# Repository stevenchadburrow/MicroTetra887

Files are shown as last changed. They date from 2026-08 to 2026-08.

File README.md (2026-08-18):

# MicroTetra887
<b>Two-player "Tetra" through 16-color VGA on a PIC16F887</b><br>

The goal of this project was a challenge to do more with less.  I have used the PIC24 and PIC32 various times to generate VGA signals and play video games, but the PIC16 has far less capability.  "Tetra" is very easy to implement and one of my favorite games, so it was the target for this device.  Space allowed for there to be two players simultaneously.

Specifications:<br>
- Only IC is the PIC16F887<br>
- Runs at 5 MIPS (20 MHz clock)<br>
- 368 bytes of RAM<br>
- VGA resolution of 24x22 pixels at 16 colors<br>
- Two-player "Tetra" through homebrew or Genesis controllers<br>
- PCB's double as both the console and controllers<br>

<table>
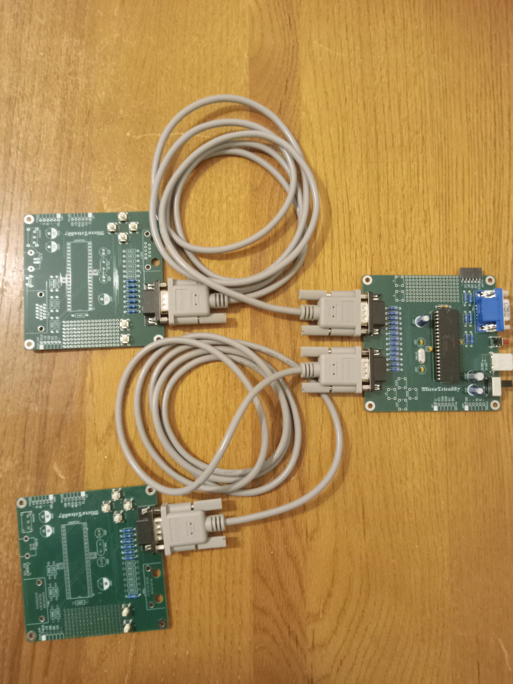
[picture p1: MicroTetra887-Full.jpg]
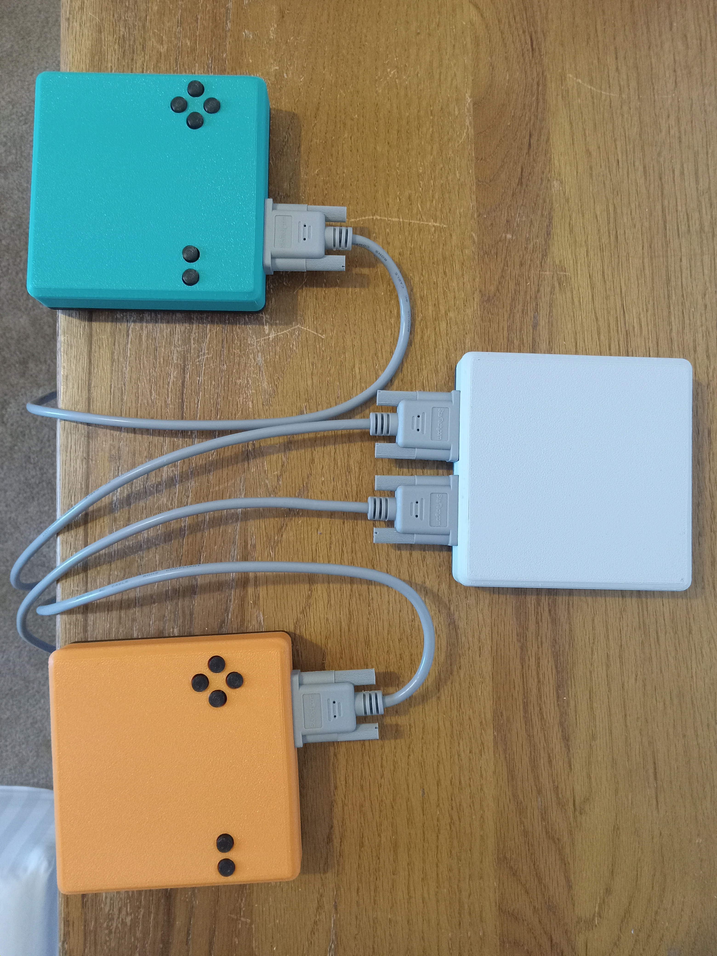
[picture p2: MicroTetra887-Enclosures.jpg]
  <tr><td></td><td></td></tr>
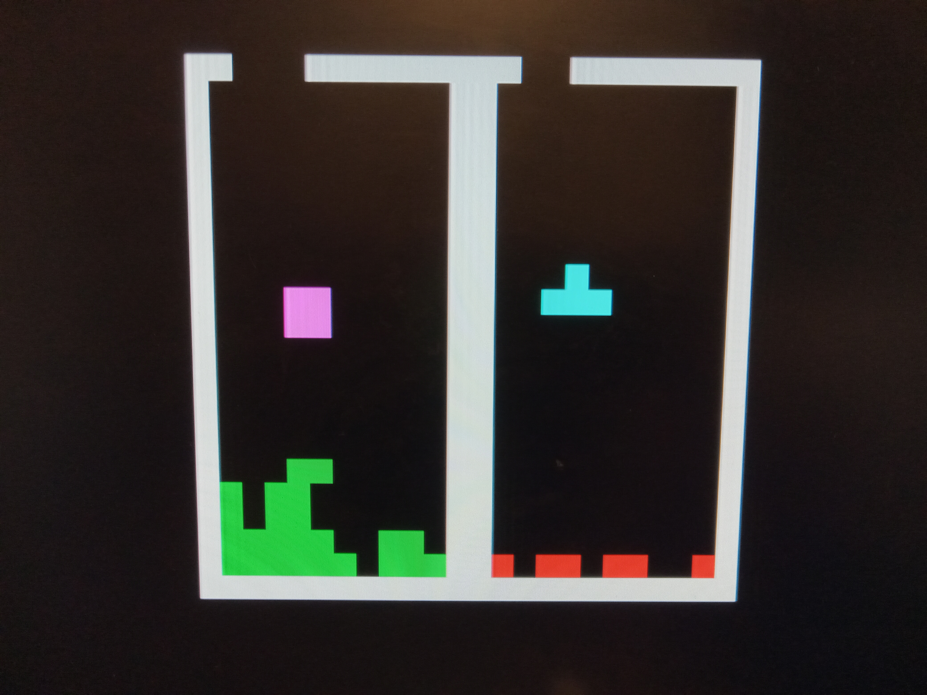
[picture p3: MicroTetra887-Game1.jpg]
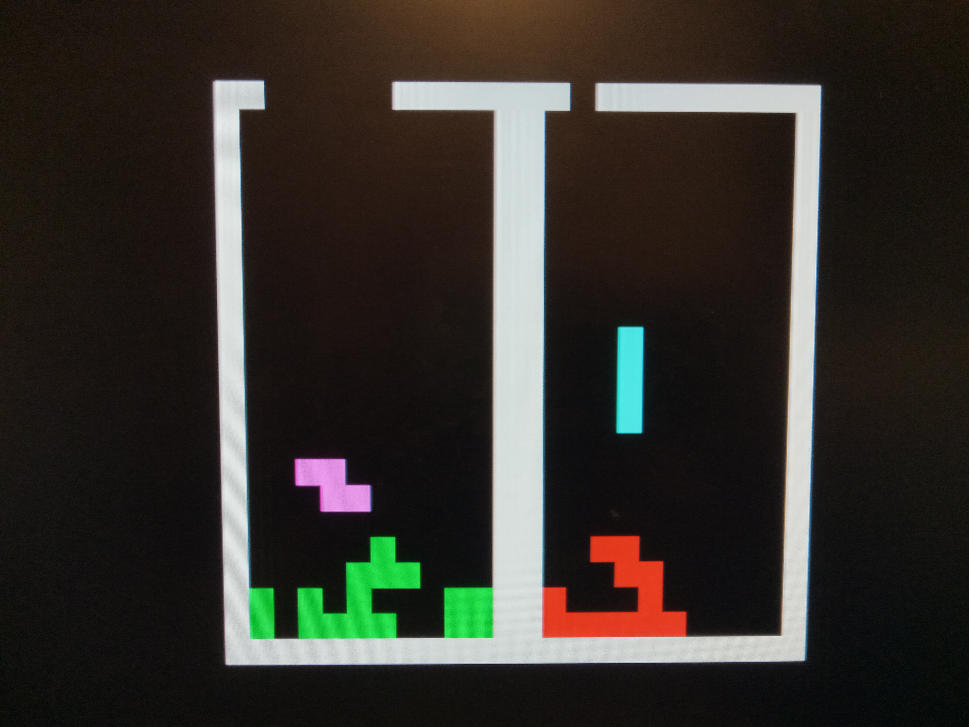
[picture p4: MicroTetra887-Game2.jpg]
  <tr><td></td><td></td></tr>
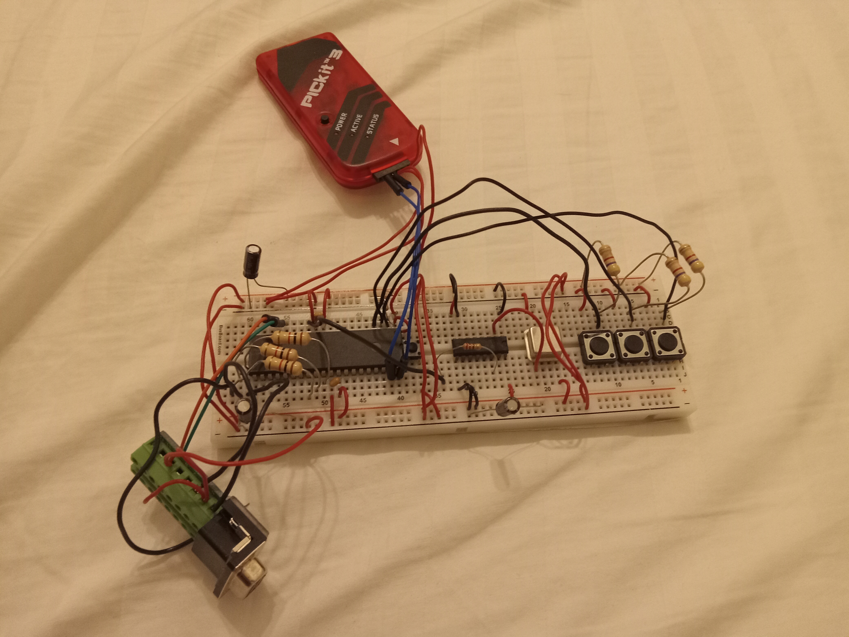
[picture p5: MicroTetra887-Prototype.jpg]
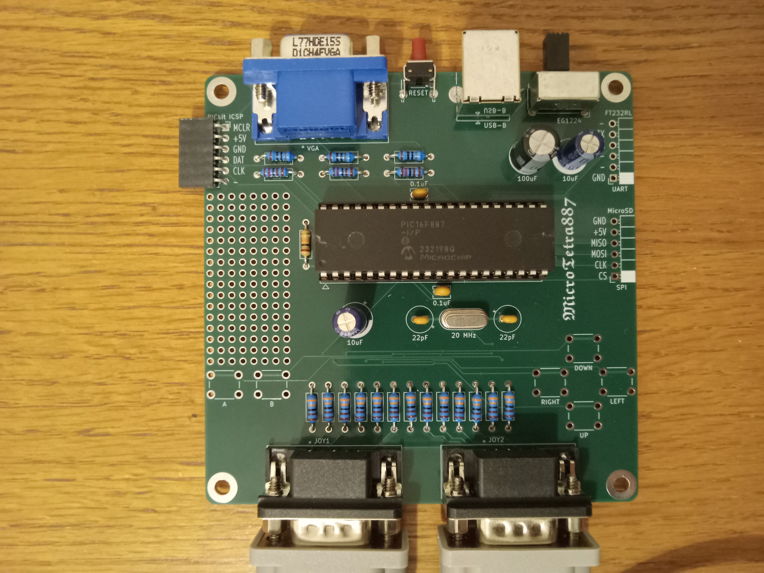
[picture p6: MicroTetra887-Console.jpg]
  <tr><td></td><td></td></tr>
</table>

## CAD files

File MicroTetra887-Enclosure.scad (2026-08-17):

// MicroTetra887

module radiusedblock(xlen,ylen,zlen,radius) {
	hull() {
		translate([radius,radius,radius]) sphere(r=radius);
		translate([xlen + radius , radius , radius]) sphere(r=radius);
		translate([radius , ylen + radius , radius]) sphere(r=radius);    
		translate([xlen + radius , ylen + radius , radius]) sphere(r=radius);
		translate([radius , radius , zlen + radius]) sphere(r=radius);
		translate([xlen + radius , radius , zlen + radius]) sphere(r=radius);
		translate([radius,ylen + radius,zlen + radius]) sphere(r=radius);
		translate([xlen + radius,ylen + radius,zlen + radius]) sphere(r=radius);
	}
}

$fn = 20; // higher detail to curves

// mode -> 0 = console, mode -> 1 = controller1, mode -> 2 = controller2
mode = 0;

// half -> 0 = both, half -> 1 = top, half -> 2 = bottom, half -> 3 = buttons
half = 0;

// up, down, left right, A, B
bpx = [ 87.5, 87.5, 95.25, 79.75, 4.75, 15.75 ];
bpy = [ 80.0, 64.5, 72.25, 72.25, 72.25, 72.25 ];

scale([1,-1,1])
{
	difference()
	{
		// outside
		translate([-5,-5,-5])
		{
			radiusedblock(100,100,20,5);
		}
		
		// inside
		translate([-1,-1,0])
		{
			cube([102,102,20]);
		}
			
        if (mode == 0)
        {
            // vga
            translate([11.0,-10,5])
            {
                cube([33.0,20,14]);
            }
            
            // reset
            translate([50.0,-10,9])
            {
                rotate([-90,0,0])
                {
                    cylinder(20,3,3);
                }
            }
                
            // usb
            translate([58.0,-10,5])
            {
                cube([14.0,20,12]);
            }
            
            // switch
            translate([77.0,-10,7])
            {
                cube([11.0,20,7]);
            }
        }
        
        if (mode == 0 || mode == 1)
        {
            // joy1
            translate([13.5,90,5])
            {
                cube([33.0,20,14]);
            }
        }
        
        if (mode == 0 || mode == 2)
        {
            // joy2
            translate([53.5,90,5])
            {
                cube([33.0,20,14]);
            }
        }
        
        if (mode == 1 || mode == 2)
        {
            // buttons
            for (i = [0:5])
            {
                translate([bpx[i], bpy[i], 10])
                {
                    cylinder(20,4,4);
                }
            }
        }
		
		// screw holes
		translate([4.0,4.0,5])
		{
			rotate([180,0,0])
			{
				cylinder(20,2.5,2.5);
			}
		}
		translate([96.0,4.0,5])
		{
			rotate([180,0,0])
			{
				cylinder(20,2.5,2.5);
			}
		}
		translate([4.0,96.0,5])
		{
			rotate([180,0,0])
			{
				cylinder(20,2.5,2.5);
			}
		}
		translate([96.0,96.0,5])
		{
			rotate([180,0,0])
			{
				cylinder(20,2.5,2.5);
			}
		}
		
        if (half == 1 || half == 3)
        {
            // comment out for top only
            translate([-10,-10,-10])
            {
                cube([120,120,10+5]);
            }
        }
		
        if (half == 2 || half == 3)
        {
            // comment out for bottom only
            translate([-10,-10,5])
            {
                cube([120,120,30]);
            }
        }
	}
	
	difference()
	{
		union()
		{
			// screw supports
			translate([4,4,0])
			{
				difference()
				{
					cylinder(20,4.5,4.5);
					cylinder(20,1.0,1.0);
				}
			}
			translate([96,4,0])
			{
				difference()
				{
					cylinder(20,4.5,4.5);
					cylinder(20,1.0,1.0);
				}
			}
			translate([4,96,0])
			{
				difference()
				{
					cylinder(20,4.5,4.5);
					cylinder(20,1.0,1.0);
				}
			}
			translate([96,96,0])
			{
				difference()
				{
					cylinder(20,4.5,4.5);
					cylinder(20,1.0,1.0);
				}
			}
			
			// support supports
			translate([1,1,0])
			{
				cylinder(20,3,3);
			}
			translate([99,1,0])
			{
				cylinder(20,3,3);
			}
			translate([1,99,0])
			{
				cylinder(20,3,3);
			}
			translate([99,99,0])
			{
				cylinder(20,3,3);
			}
			
            if (mode == 1 || mode == 2)
            {
                // button supports
                for (i = [0:5])
                {
                    translate([bpx[i], bpy[i], 15])
                    {
                        difference()
                        {
                            cylinder(5,6,6);
                            cylinder(5,4,4);
                        }
                    }
                }
            }
		}
		
		// pcb
		translate([-10,-10,5-1.6])
		{
			cube([120,120,1.6]);
		}
		
        if (half == 1 || half == 3)
        {
            // comment out for top only
            translate([-10,-10,-10])
            {
                cube([120,120,10+5]);
            }
        }
		
        if (half == 2 || half == 3)
        {
            // comment out for bottom only
            translate([-10,-10,5])
            {
                cube([120,120,30]);
            }
        }
	}
}

module button()
{
	difference()
	{
		union()
		{
			cylinder(15, 3.5, 3.5);
			cylinder(2, 5, 5);
			intersection()
			{
				sphere(17);
				cylinder(100, 3.5, 3.5);
			}
		}
		translate([-1.35, -1.35, 0])
		{
			cube([2.7, 2.7, 3.0]);
		}
	}
}

if (half == 3)
{
    button();
}

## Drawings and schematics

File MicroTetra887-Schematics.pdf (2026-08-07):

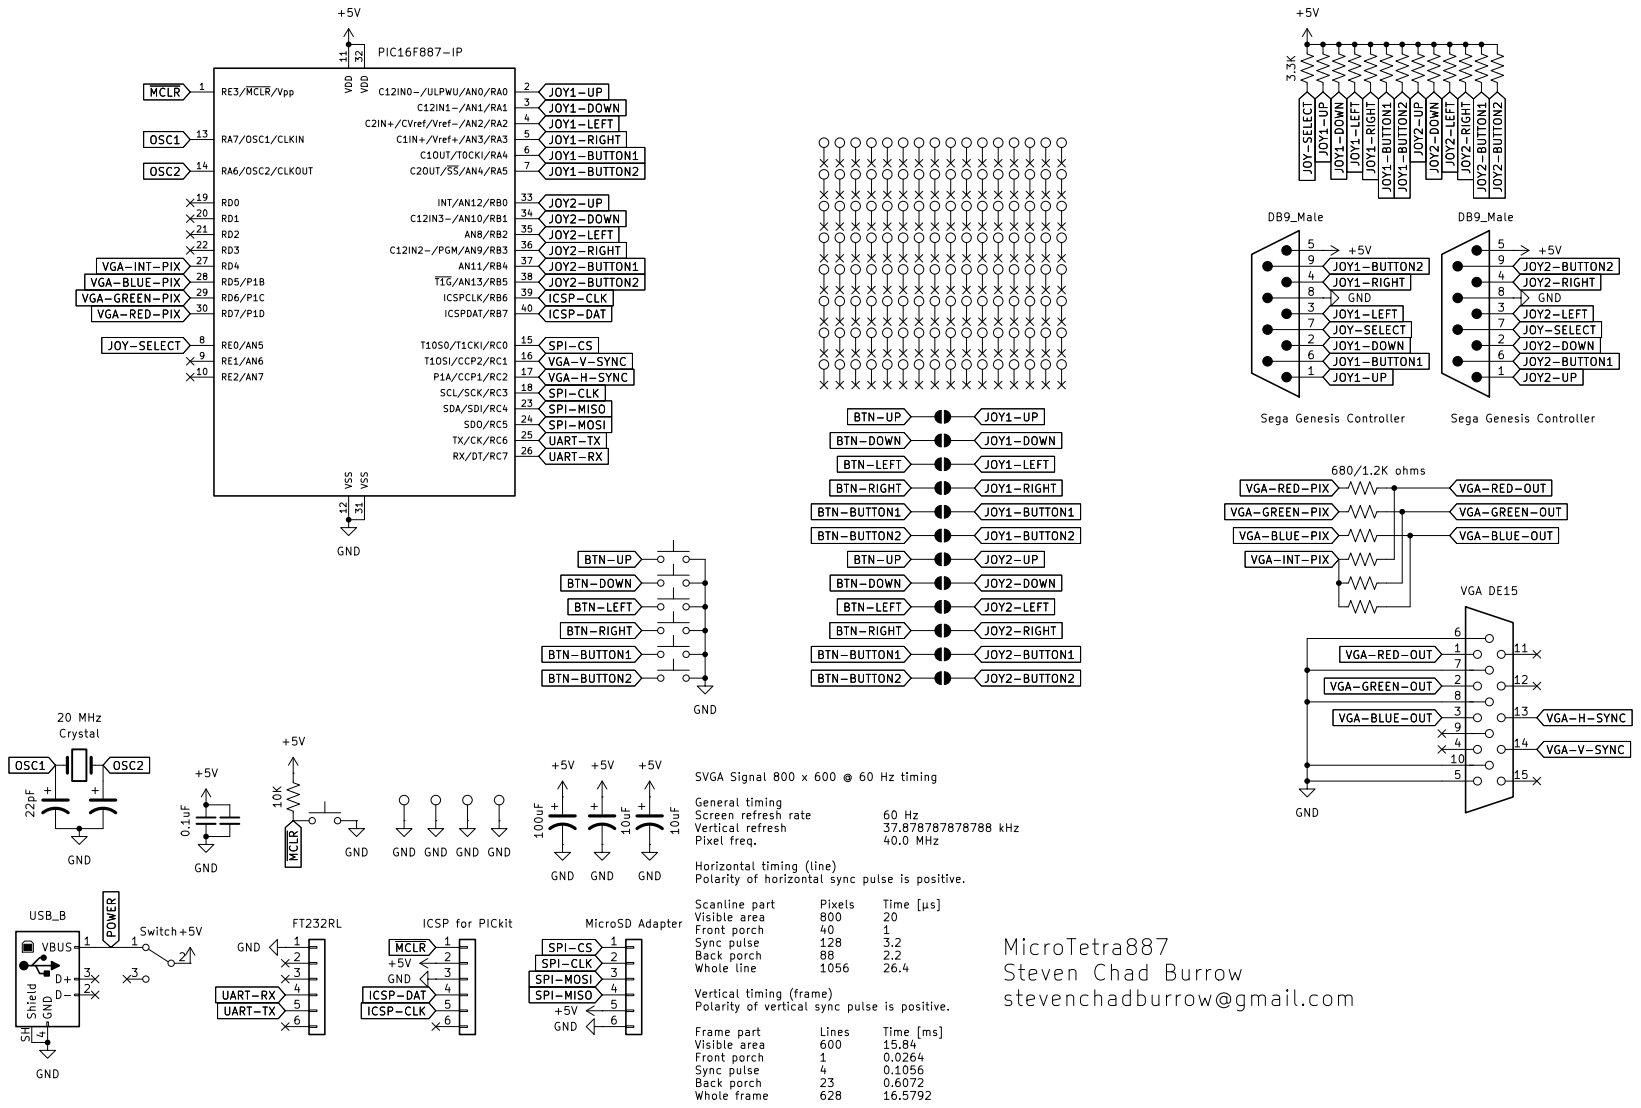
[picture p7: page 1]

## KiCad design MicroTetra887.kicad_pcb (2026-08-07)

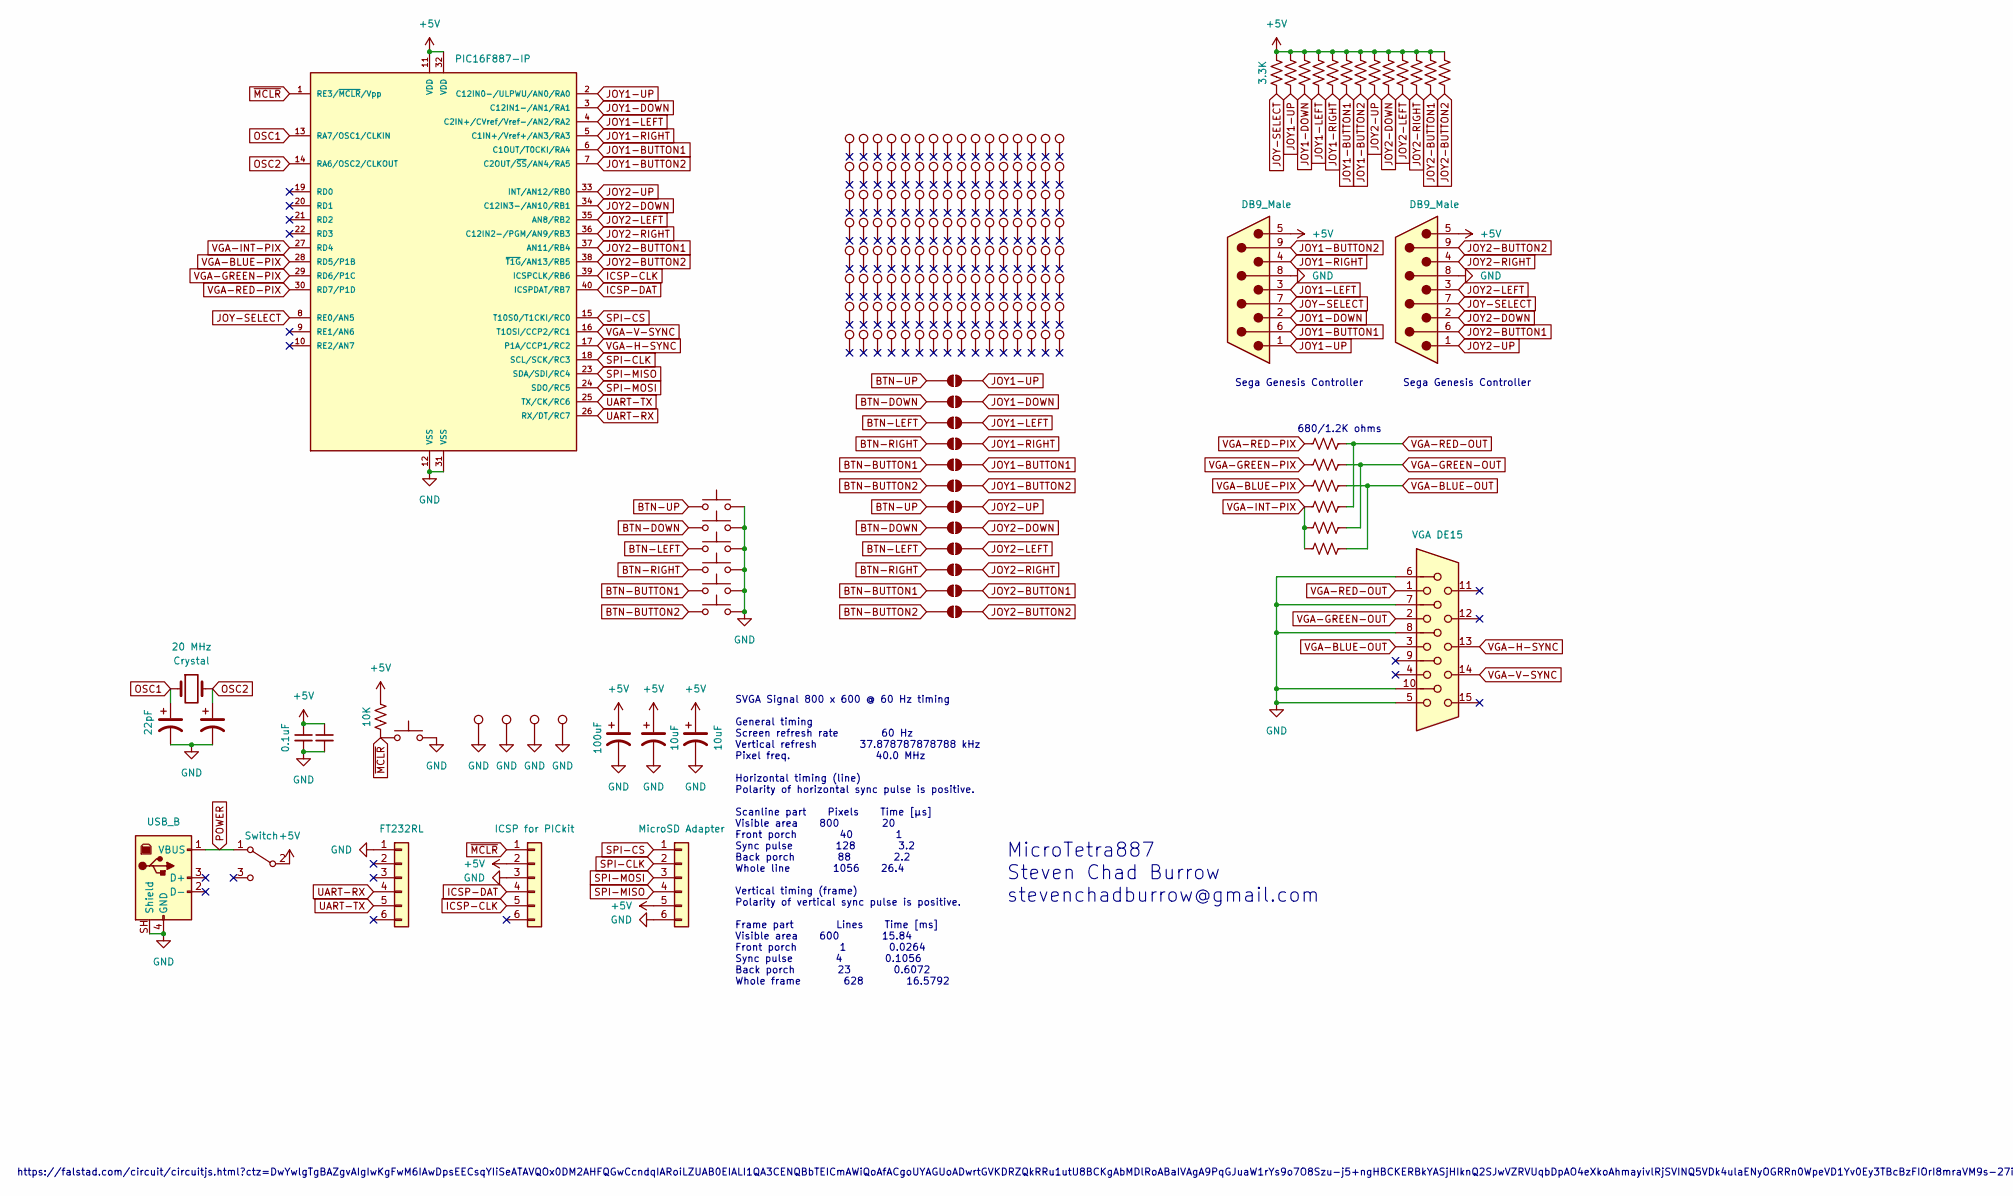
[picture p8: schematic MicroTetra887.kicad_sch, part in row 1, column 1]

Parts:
C1, C2: C_Polarized_US; CP_Radial_Tantal_D6.0mm_P2.50mm
C3, C4, C5: C_Polarized_US; CP_Radial_D8.0mm_P3.50mm
C8, C9: C_Small; C_Disc_D3.8mm_W2.6mm_P2.50mm
J1: USB_B; USB_B_Lumberg_2411_02_Horizontal
J8, J9: DB9_Male; DSUB-9_Pins_Horizontal_P2.77x2.84mm_EdgePinOffset7.70mm_Hou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
J11: VGA DE15; DSUB-15-HD_Socket_Horizontal_P2.29x2.54mm_EdgePinOffset8.35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
J14, J15, J16: Conn_01x06; PinSocket_1x06_P2.54mm_Horizontal
JP1, JP2, JP3, JP4, JP5, JP6, JP7, JP8, JP9, JP10, JP11, JP12: SolderJumper_2_Open; SolderJumper-2_P1.3mm_Open_Pad1.0x1.5mm
R9, R10, R11, R14, R15, R16, R17, R18, R19, R20, R21, R22, R23, R24, R25, R26, R27, R28, R29, R30: R_US; R_Axial_DIN0207_L6.3mm_D2.5mm_P10.16mm_Horizontal
SW1, SW2, SW3, SW4, SW5, SW6: SW_Push; SW_PUSH_6mm_H13mm
SW7: SW_SPDT; SW_E-Switch_EG1224_SPDT_Angled
SW11: SW_Push; SW_Tactile_SPST_Angled_PTS645Vx83-2LFS
TP1, TP2, TP3, TP4: TestPoint; ScrewHole-4-40
TP5, TP6, TP7, TP8, TP9, TP10, TP11, TP12, TP13, TP14, TP15, TP16, TP17, TP18, TP19, TP20, TP21, TP22, TP23, TP24, TP25, TP26, TP27, TP28, TP29, TP30, TP31, TP32, TP33, TP34, TP35, TP36, TP37, TP38, TP39, TP40, TP41, TP42, TP43, TP44, TP45, TP46, TP47, TP48, TP49, TP50, TP51, TP52, TP53, TP54, TP55, TP56, TP57, TP58, TP59, TP60, TP61, TP62, TP63, TP64, TP65, TP66, TP67, TP68, TP69, TP70, TP71, TP72, TP73, TP74, TP75, TP76, TP77, TP78, TP79, TP80, TP81, TP82, TP83, TP84, TP85, TP86, TP87, TP88, TP89, TP90, TP91, TP92, TP93, TP94, TP95, TP96, TP97, TP98, TP99, TP100, TP101, TP102, TP103, TP104, TP105, TP106, TP107, TP108, TP109, TP110, TP111, TP112, TP113, TP114, TP115, TP116, TP117, TP118, TP119, TP120, TP121, TP122, TP123, TP124, TP125, TP126, TP127, TP128, TP129, TP130, TP131, TP132: TestPoint; PinHeader_1x01_P2.54mm_Vertical_TestPoint
U1: PIC16F887-IP; DIP-40_W15.24mm_Socket
Y1: Crystal; Crystal_HC18-U_Vertical

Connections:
+5V: C3.1, C4.1, C5.1, C8.1, C9.1, J8.5, J9.5, J14.2, J16.5, R11.1, R18.1, R19.1, R20.1, R21.1, R22.1, R23.1, R24.1, R25.1, R26.1, R27.1, R28.1, R29.1, R30.1, SW7.2 (B), U1.11 (VDD), U1.32 (VDD)
BTN-BUTTON1: JP5.1 (A), JP11.1 (A), SW5.1
BTN-BUTTON2: JP6.1 (A), JP12.1 (A), SW6.1
BTN-DOWN: JP2.1 (A), JP8.1 (A), SW2.1
BTN-LEFT: JP3.1 (A), JP9.1 (A), SW3.1
BTN-RIGHT: JP4.1 (A), JP10.1 (A), SW4.1
BTN-UP: JP1.1 (A), JP7.1 (A), SW1.1
GND: C1.2, C2.2, C3.2, C4.2, C5.2, C8.2, C9.2, J1.4 (GND), J1.SH (Shield), J8.8, J9.8, J11.5, J11.6, J11.7, J11.8, J11.10, J14.3, J15.1, J16.6, SW1.2, SW2.2, SW3.2, SW4.2, SW5.2, SW6.2, SW11.2, TP1.1 (1_1), TP2.1 (1_1), TP3.1 (1_1), TP4.1 (1_1), U1.12 (VSS), U1.31 (VSS)
ICSP-CLK: J14.5, U1.39 (ICSPCLK/RB6)
ICSP-DAT: J14.4, U1.40 (ICSPDAT/RB7)
JOY1-BUTTON1: J8.6, JP5.2 (B), R23.2, U1.6 (C1OUT/T0CKI/RA4)
JOY1-BUTTON2: J8.9, JP6.2 (B), R24.2, U1.7 (C2OUT/~SS/AN4/RA5)
JOY1-DOWN: J8.2, JP2.2 (B), R20.2, U1.3 (C12IN1-/AN1/RA1)
JOY1-LEFT: J8.3, JP3.2 (B), R21.2, U1.4 (C2IN+/CVref/Vref-/AN2/RA2)
JOY1-RIGHT: J8.4, JP4.2 (B), R22.2, U1.5 (C1IN+/Vref+/AN3/RA3)
JOY1-UP: J8.1, JP1.2 (B), R19.2, U1.2 (C12IN0-/ULPWU/AN0/RA0)
JOY2-BUTTON1: J9.6, JP11.2 (B), R29.2, U1.37 (AN11/RB4)
JOY2-BUTTON2: J9.9, JP12.2 (B), R30.2, U1.38 (~T1G/AN13/RB5)
JOY2-DOWN: J9.2, JP8.2 (B), R26.2, U1.34 (C12IN3-/AN10/RB1)
JOY2-LEFT: J9.3, JP9.2 (B), R27.2, U1.35 (AN8/RB2)
JOY2-RIGHT: J9.4, JP10.2 (B), R28.2, U1.36 (C12IN2-/PGM/AN9/RB3)
JOY2-UP: J9.1, JP7.2 (B), R25.2, U1.33 (INT/AN12/RB0)
JOY-SELECT: J8.7, J9.7, R18.2, U1.8 (RE0/AN5)
OSC1: C1.1, U1.13 (RA7/OSC1/CLKIN), Y1.1
OSC2: C2.1, U1.14 (RA6/OSC2/CLKOUT), Y1.2
POWER: J1.1 (VBUS), SW7.1 (A)
SPI-CLK: J16.2, U1.18 (SCL/SCK/RC3)
SPI-CS: J16.1, U1.15 (T10S0/T1CKI/RC0)
SPI-MISO: J16.4, U1.23 (SDA/SDI/RC4)
SPI-MOSI: J16.3, U1.24 (SDO/RC5)
UART-RX: J15.4, U1.26 (RX/DT/RC7)
UART-TX: J15.5, U1.25 (TX/CK/RC6)
VGA-BLUE-OUT: J11.3, R16.1, R17.1
VGA-BLUE-PIX: R16.2, U1.28 (RD5/P1B)
VGA-GREEN-OUT: J11.2, R14.1, R15.1
VGA-GREEN-PIX: R14.2, U1.29 (RD6/P1C)
VGA-H-SYNC: J11.13, U1.17 (P1A/CCP1/RC2)
VGA-INT-PIX: R10.2, R15.2, R17.2, U1.27 (RD4)
VGA-RED-OUT: J11.1, R9.1, R10.1
VGA-RED-PIX: R9.2, U1.30 (RD7/P1D)
VGA-V-SYNC: J11.14, U1.16 (T1OSI/CCP2/RC1)
~MCLR: J14.1, R11.2, SW11.1, U1.1 (RE3/~MCLR/Vpp)

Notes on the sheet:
MicroTetra887 Steven Chad Burrow stevenchadburrow@gmail.com
Sega Genesis Controller
https://falstad.com/circuit/circuitjs.html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…
680/1.2K ohms
SVGA Signal 800 x 600 @ 60 Hz timing General timing Screen refresh rate 60 Hz Vertical refresh 37.878787878788 kHz Pixel freq. 40.0 MHz Horizontal timing (line) Polarity of horizontal sync pulse is positive. Scanline part Pixels Time [µs] Visible area 800 20 Front porch 40 1 Sync pulse 128 3.2 Back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

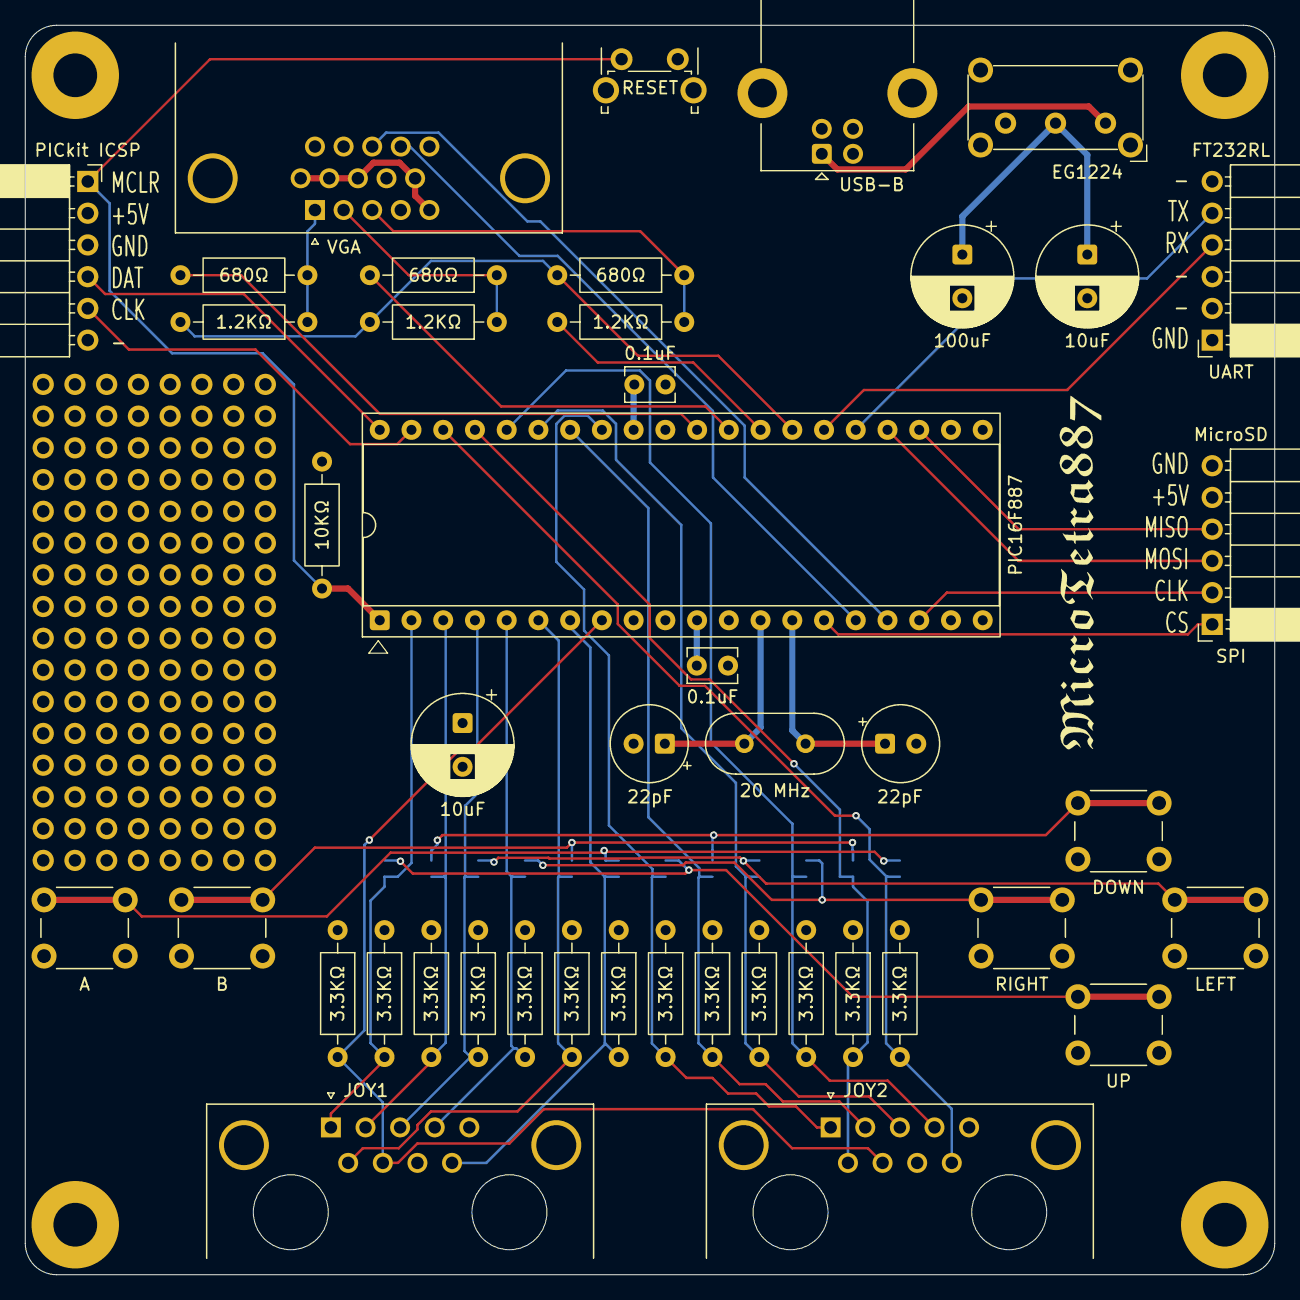
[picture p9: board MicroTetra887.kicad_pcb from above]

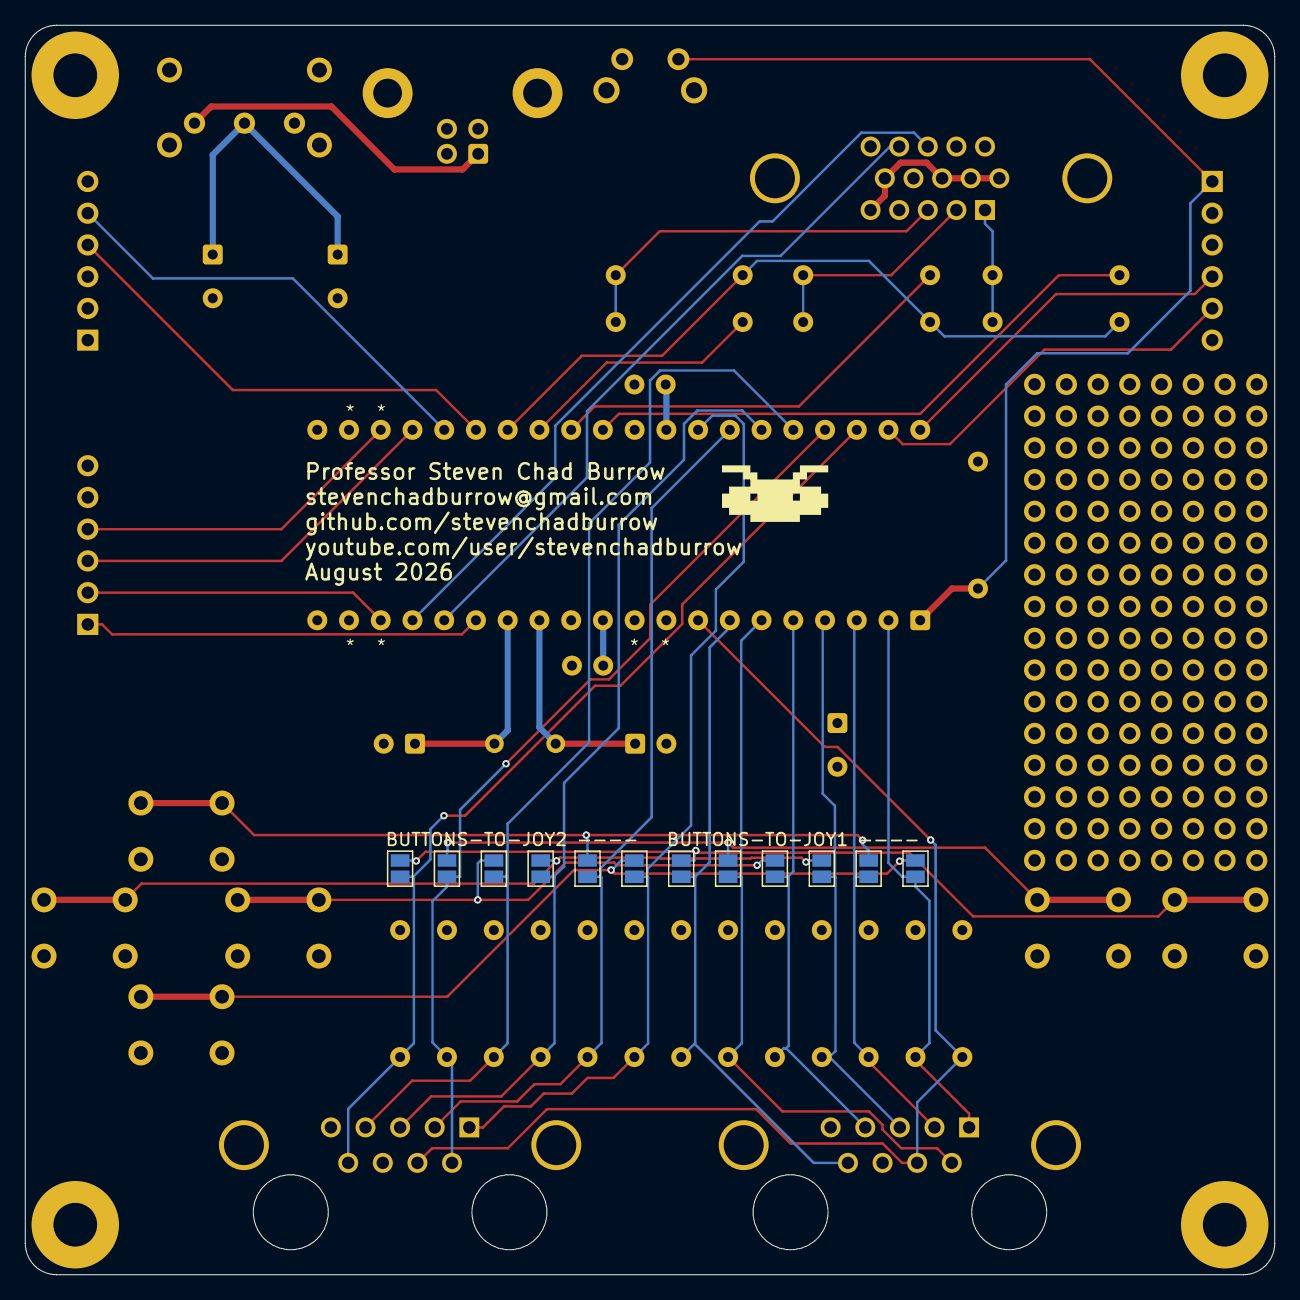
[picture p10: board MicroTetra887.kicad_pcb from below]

Board: 4 copper layers, 100.0 x 100.0 mm, 190 parts (13 on the bottom side), 42 nets.

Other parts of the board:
G100: LOGO; Logo
G101: LOGO; Title

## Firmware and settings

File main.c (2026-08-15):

// To program with the TL866II:
// minipro -p PIC16F887@DIP40 -w dist/default/production/MicroTetra887.X.production.hex

// Else, program using the PICkit3 using MPLAB X IDE v6.20 or earlier

// PIC16F887 Configuration Bit Settings

// 'C' source line config statements

// CONFIG1
//#pragma config FOSC = INTRC_NOCLKOUT// Oscillator Selection bits (INTOSCIO oscillator: I/O function on RA6/OSC2/CLKOUT pin, I/O function on RA7/OSC1/CLKIN)
#pragma config FOSC = HS        // Oscillator Selection bits (HS oscillator: High-speed crystal/resonator on RA6/OSC2/CLKOUT and RA7/OSC1/CLKIN)
#pragma config WDTE = OFF       // Watchdog Timer Enable bit (WDT disabled and can be enabled by SWDTEN bit of the WDTCON register)
#pragma config PWRTE = OFF      // Power-up Timer Enable bit (PWRT disabled)
#pragma config MCLRE = ON       // RE3/MCLR pin function select bit (RE3/MCLR pin function is MCLR)
#pragma config CP = OFF         // Code Protection bit (Program memory code protection is disabled)
#pragma config CPD = OFF        // Data Code Protection bit (Data memory code protection is disabled)
#pragma config BOREN = OFF      // Brown Out Reset Selection bits (BOR disabled)
#pragma config IESO = ON        // Internal External Switchover bit (Internal/External Switchover mode is enabled)
#pragma config FCMEN = OFF      // Fail-Safe Clock Monitor Enabled bit (Fail-Safe Clock Monitor is disabled)
#pragma config LVP = OFF        // Low Voltage Programming Enable bit (RB3 pin has digital I/O, HV on MCLR must be used for programming)

// CONFIG2
#pragma config BOR4V = BOR40V   // Brown-out Reset Selection bit (Brown-out Reset set to 4.0V)
#pragma config WRT = OFF        // Flash Program Memory Self Write Enable bits (Write protection off)

// #pragma config statements should precede project file includes.
// Use project enums instead of #define for ON and OFF.

#include <xc.h>

#include <pic16f887.h>


// bank 0 variables
unsigned char __at(0x0050) vert;
unsigned char __at(0x0051) scale;
unsigned char __at(0x0052) vsync;

// bank 2 variables
unsigned char __at(0x0110) piece[2];
unsigned char __at(0x0112) posx[2];
unsigned char __at(0x0114) posy[2];
unsigned char __at(0x0116) rot[2];
unsigned char __at(0x0118) delay[2];
unsigned char __at(0x011A) score[2];
unsigned char __at(0x011C) grav[2];
unsigned char __at(0x011E) bag[2];

// common memory for all banks
unsigned char __at(0x0070) pixel[12];

// banked frame buffer memory
unsigned char __at(0x0020) field0[48];
unsigned char __at(0x00A0) field1[72];
unsigned char __at(0x0120) field2[72];
unsigned char __at(0x01A0) field3[72];

// temporary values
unsigned char i, j, k, l, p;

// piece mappings
const unsigned char map_jli[160] = {
	0x00, 0x00, 0xFF, 0x00, // j
	0x00, 0x00, 0xFF, 0x00,
	0x00, 0xFF, 0xFF, 0x00,
	0x00, 0x00, 0x00, 0x00,

	0x00, 0x00, 0x00, 0x00,
	0xFF, 0xFF, 0xFF, 0x00,
	0x00, 0x00, 0xFF, 0x00,
	0x00, 0x00, 0x00, 0x00,

	0x00, 0x00, 0x00, 0x00,
	0x00, 0xFF, 0xFF, 0x00,
	0x00, 0xFF, 0x00, 0x00,
	0x00, 0xFF, 0x00, 0x00,

	0x00, 0x00, 0x00, 0x00,
	0x00, 0xFF, 0x00, 0x00,
	0x00, 0xFF, 0xFF, 0xFF,
	0x00, 0x00, 0x00, 0x00,

	0x00, 0xFF, 0x00, 0x00, // l
	0x00, 0xFF, 0x00, 0x00,
	0x00, 0xFF, 0xFF, 0x00,
	0x00, 0x00, 0x00, 0x00,

	0x00, 0x00, 0x00, 0x00,
	0x00, 0x00, 0xFF, 0x00,
	0xFF, 0xFF, 0xFF, 0x00,
	0x00, 0x00, 0x00, 0x00,

	0x00, 0x00, 0x00, 0x00,
	0x00, 0xFF, 0xFF, 0x00,
	0x00, 0x00, 0xFF, 0x00,
	0x00, 0x00, 0xFF, 0x00,

	0x00, 0x00, 0x00, 0x00,
	0x00, 0xFF, 0xFF, 0xFF,
	0x00, 0xFF, 0x00, 0x00,
	0x00, 0x00, 0x00, 0x00,

	0x00, 0xFF, 0x00, 0x00, // i
	0x00, 0xFF, 0x00, 0x00,
	0x00, 0xFF, 0x00, 0x00,
	0x00, 0xFF, 0x00, 0x00,

	0x00, 0x00, 0x00, 0x00,
	0xFF, 0xFF, 0xFF, 0xFF,
	0x00, 0x00, 0x00, 0x00,
	0x00, 0x00, 0x00, 0x00,
};

const unsigned char map_szt[72] = {
	0x00, 0xFF, 0xFF, // s
	0xFF, 0xFF, 0x00,
	0x00, 0x00, 0x00,

	0xFF, 0x00, 0x00,
	0xFF, 0xFF, 0x00,
	0x00, 0xFF, 0x00,

	0xFF, 0xFF, 0x00, // z
	0x00, 0xFF, 0xFF,
	0x00, 0x00, 0x00,

	0x00, 0x00, 0xFF,
	0x00, 0xFF, 0xFF,
	0x00, 0xFF, 0x00,

	0x00, 0xFF, 0x00, // t
	0xFF, 0xFF, 0xFF,
	0x00, 0x00, 0x00,

	0x00, 0xFF, 0x00,
	0xFF, 0xFF, 0x00,
	0x00, 0xFF, 0x00,

	0x00, 0x00, 0x00,
	0xFF, 0xFF, 0xFF,
	0x00, 0xFF, 0x00,

	0x00, 0xFF, 0x00,
	0x00, 0xFF, 0xFF,
	0x00, 0xFF, 0x00,
};

const unsigned char map_o[6] = {
	0x00, 0xFF, 0xFF,
	0x00, 0xFF, 0xFF,
};

// sub-routines in assembly, draws scanlines without exiting until finished
// resolution of 24x22 at 16-colors, each block is 16x16 real pixels
extern void scanlines(void);
extern void table_bank(void);
extern void table_line(void);

// interrupt for H-SYNC and V-SYNC signals
void __interrupt() ISR(void)
{
	if (PIR1bits.TMR1IF == 1) // check flag
	{
		PIR1bits.TMR1IF = 0; // clear flag

		if (vsync == 0 || vsync == 3) // sync pulse
		{
			PORTCbits.RC1 = 1; // V-SYNC positive

			// set TMR1 interrupt
			T1CON = 0x10; // prescaler = 1:2, disable timer
			TMR1H = 0xFE; // 0x10000 - [4 * 1056 / (2 * 4 * 2) - 1] = 65536 - 263 = 0xFEF9
			TMR1L = 0xF9;
			T1CONbits.TMR1ON = 1; // turn on timer

			// disable PWM signal and ground H-SYNC
			CCP1CON = 0x00; // disable PWM
			PORTCbits.RC2 = 0; // ground H-SYNC signal

			// nop padding
			asm("NOP");
			asm("NOP");
			asm("NOP");
			asm("NOP");
			asm("NOP");
			asm("NOP");
			asm("NOP");
			asm("NOP");

			// set H-SYNC high
			PORTCbits.RC2 = 1;

			// nop padding
			asm("NOP");
			asm("NOP");
			asm("NOP");
			asm("NOP");

			// set TMR2 for PWM signal to H-SYNC
			T2CON = 0x00; // prescaler = 1:1, postscaler = 1:1, disable timer
			PR2 = 0x83; // 1056 / (2 * 4) - 1 = 131 = 0x83
			TMR2 = 0x00; // clear timer2
			CCP1CON = 0x0C; // PWM mode, 00 for LSBs, P1A active high
			CCPR1L = 0x10; // pulse width = 128 / (2) >> 2 = 64 >> 2 = 0x10
			PIR1bits.TMR2IF = 0; // clear interrupt flag
			T2CONbits.TMR2ON = 1; // turn on timer2
			while (PIR1bits.TMR2IF == 0) { } // wait until overflow

			vsync = 1;
		}
		else if (vsync == 1) // back porch
		{
			PORTCbits.RC1 = 0; // V-SYNC negative
	
			// set TMR1 interrupt
			T1CON = 0x10; // prescaler = 1:2, disable timer
			TMR1H = 0xE0; // 0x10000 - [(23+100) * 1056 / (2 * 4 * 2) - 1] = 65536 - 8117 = 57419 = 0xE04B
			TMR1L = 0x4B;
			T1CONbits.TMR1ON = 1; // turn on timer

			vsync = 2;
		}
		else if (vsync == 2) // visible area and front porch
		{
			// set TMR1 interrupt
			T1CON = 0x10; // prescaler = 1:2, disable timer
			TMR1H = 0x7E; // 0x10000 - [(601-100) * 1056 / (2 * 4 * 2) - 1] = 65536 - 33065 = 32471 = 0x7ED7
			TMR1L = 0xD7;
			T1CONbits.TMR1ON = 1; // turn on timer

			// start drawing scanlines
			asm("CLRW"); // make sure to clear W
			asm("CLRF 0x03"); // and start in bank 0
			scanlines(); // jumps to assembly file

			vsync = 0;
		}
	}
}

// must duplicate upper and lower nibbles of c
void block_write(unsigned char x, unsigned char y, unsigned char c)
{
	if (y < 4) // field0
	{
		l = (unsigned char)((y<<3)+(y<<2)+(x>>1));

		if ((x & 0x01) == 0x00) // even
		{
			field0[l] = (field0[l] & 0x0F) | (c & 0xF0);
		}
		else // odd
		{
			field0[l] = (field0[l] & 0xF0) | (c & 0x0F);
		}
	}
	else if (y < 10) // field1
	{
		l = (unsigned char)(((y-4)<<3)+((y-4)<<2)+(x>>1));

		if ((x & 0x01) == 0x00) // even
		{
			field1[l] = (field1[l] & 0x0F) | (c & 0xF0);
		}
		else // odd
		{
			field1[l] = (field1[l] & 0xF0) | (c & 0x0F);
		}
	}
	else if (y < 16) // field2
	{
		l = (unsigned char)(((y-10)<<3)+((y-10)<<2)+(x>>1));

		if ((x & 0x01) == 0x00) // even
		{
			field2[l] = (field2[l] & 0x0F) | (c & 0xF0);
		}
		else // odd
		{
			field2[l] = (field2[l] & 0xF0) | (c & 0x0F);
		}
	}
	else // field3
	{
		l = (unsigned char)(((y-16)<<3)+((y-16)<<2)+(x>>1));

		if ((x & 0x01) == 0x00) // even
		{
			field3[l] = (field3[l] & 0x0F) | (c & 0xF0);
		}
		else // odd
		{
			field3[l] = (field3[l] & 0xF0) | (c & 0x0F);
		}
	}
};

// duplicates upper and lower nibbles of c
unsigned char block_read(unsigned char x, unsigned char y)
{
	if (y < 4) // field0
	{
		l = (unsigned char)((y<<3)+(y<<2)+(x>>1));

		if ((x & 0x01) == 0x00) // even
		{
			return (unsigned char)((field0[l] & 0xF0) | ((field0[l] & 0xF0) >> 4));
		}
		else // odd
		{
			return (unsigned char)((field0[l] & 0x0F) | ((field0[l] & 0x0F) << 4));
		}
	}
	else if (y < 10) // field1
	{
		l = (unsigned char)(((y-4)<<3)+((y-4)<<2)+(x>>1));

		if ((x & 0x01) == 0x00) // even
		{
			return (unsigned char)((field1[l] & 0xF0) | ((field1[l] & 0xF0) >> 4));
		}
		else // odd
		{
			return (unsigned char)((field1[l] & 0x0F) | ((field1[l] & 0x0F) << 4));
		}
	}
	else if (y < 16) // field2
	{
		l = (unsigned char)(((y-10)<<3)+((y-10)<<2)+(x>>1));

		if ((x & 0x01) == 0x00) // even
		{
			return (unsigned char)((field2[l] & 0xF0) | ((field2[l] & 0xF0) >> 4));
		}
		else // odd
		{
			return (unsigned char)((field2[l] & 0x0F) | ((field2[l] & 0x0F) << 4));
		}
	}
	else // field3
	{
		l = (unsigned char)(((y-16)<<3)+((y-16)<<2)+(x>>1));

		if ((x & 0x01) == 0x00) // even
		{
			return (unsigned char)((field3[l] & 0xF0) | ((field3[l] & 0xF0) >> 4));
		}
		else // odd
		{
			return (unsigned char)((field3[l] & 0x0F) | ((field3[l] & 0x0F) << 4));
		}
	}

	return 0x00;
};

// duplicates upper and lower nibbles of c
void block_replace(unsigned char x, unsigned char y, unsigned char a, unsigned char b)
{
	if (y < 4) // field0
	{
		l = (unsigned char)((y<<3)+(y<<2)+(x>>1));

		if ((x & 0x01) == 0x00) // even
		{
			if ((field0[l] & 0xF0) == (a & 0xF0)) field0[l] = (field0[l] & 0x0F) | (b & 0xF0);
		}
		else // odd
		{
			if ((field0[l] & 0x0F) == (a & 0x0F)) field0[l] = (field0[l] & 0xF0) | (b & 0x0F);
		}
	}
	else if (y < 10) // field1
	{
		l = (unsigned char)(((y-4)<<3)+((y-4)<<2)+(x>>1));

		if ((x & 0x01) == 0x00) // even
		{
			if ((field1[l] & 0xF0) == (a & 0xF0)) field1[l] = (field1[l] & 0x0F) | (b & 0xF0);
		}
		else // odd
		{
			if ((field1[l] & 0x0F) == (a & 0x0F)) field1[l] = (field1[l] & 0xF0) | (b & 0x0F);
		}
	}
	else if (y < 16) // field2
	{
		l = (unsigned char)(((y-10)<<3)+((y-10)<<2)+(x>>1));

		if ((x & 0x01) == 0x00) // even
		{
			if ((field2[l] & 0xF0) == (a & 0xF0)) field2[l] = (field2[l] & 0x0F) | (b & 0xF0);
		}
		else // odd
		{
			if ((field2[l] & 0x0F) == (a & 0x0F)) field2[l] = (field2[l] & 0xF0) | (b & 0x0F);
		}
	}
	else // field3
	{
		l = (unsigned char)(((y-16)<<3)+((y-16)<<2)+(x>>1));

		if ((x & 0x01) == 0x00) // even
		{
			if ((field3[l] & 0xF0) == (a & 0xF0)) field3[l] = (field3[l] & 0x0F) | (b & 0xF0);
		}
		else // odd
		{
			if ((field3[l] & 0x0F) == (a & 0x0F)) field3[l] = (field3[l] & 0xF0) | (b & 0x0F);
		}
	}
};

#define P1COL1 0xBB // bright magenta
#define P1COL2 0x44 // dark green
#define P2COL1 0x77 // bright cyan
#define P2COL2 0x88 // dark red

// needs a 20 MHz crystal
void main(void)
{
	// turn off analog
	ANSEL = 0x00; // turn off analog
	ANSELH = 0x00;

	// initial settings for all pins
	PORTA = 0x00;
	TRISA = 0xFF; // JOY1, CRYSTAL
	PORTB = 0x00;
	TRISB = 0xFF; // JOY2, ISCP
	PORTC = 0x06;
	TRISC = 0x80; // RX/TX, SPI, H-SYNC/V-SYNC
	PORTD = 0x00;
	TRISD = 0x0F; // VGA
	PORTE = 0x01;
	TRISE = 0x01; // JOY-SELECT

	// disable interrupts
	OPTION_REG = 0x00;
	INTCON = 0x00;
	PIE1 = 0x00;
	PIE2 = 0x00;
	PCON = 0x03;

	// set up memory
	for (i=0; i<48; i++)
	{
		if (i < 12)
		{
			field0[i] = 0xFF;
		}
		else
		{
			if (i % 12 == 0 || i % 12 == 6) field0[i] = (unsigned char)0xF0;
			else if (i % 12 == 5 || i % 12 == 11) field0[i] = (unsigned char)0x0F;
			else field0[i] = (unsigned char)0x00;
		}
	}

	for (i=0; i<72; i++)
	{
		if (i % 12 == 0 || i % 12 == 6) field1[i] = (unsigned char)0xF0;
		else if (i % 12 == 5 || i % 12 == 11) field1[i] = (unsigned char)0x0F;
		else field1[i] = (unsigned char)0x00;
	}

	for (i=0; i<72; i++)
	{
		if (i % 12 == 0 || i % 12 == 6) field2[i] = (unsigned char)0xF0;
		else if (i % 12 == 5 || i % 12 == 11) field2[i] = (unsigned char)0x0F;
		else field2[i] = (unsigned char)0x00;
	}

	for (i=0; i<72; i++)
	{
		if (i < 60)
		{
			if (i % 12 == 0 || i % 12 == 6) field3[i] = (unsigned char)0xF0;
			else if (i % 12 == 5 || i % 12 == 11) field3[i] = (unsigned char)0x0F;
			else field3[i] = (unsigned char)0x00;
		}
		else field3[i] = (unsigned char)0xFF;
	}

	// set TMR1 interrupt for V-SYNC
	T1CON = 0x10; // prescaler = 1:2, disable timer
	TMR1H = 0xFE; // 0x10000 - [4 * 1056 / (2 * 4 * 2) - 1] = 65536 - 263 = 0xFEF9
	TMR1L = 0xF9;
	PIR1bits.TMR1IF = 0; // clear flag
	PIE1bits.TMR1IE = 1; // turn on TMR1 interrupts
	INTCONbits.PEIE = 1; // turn on peripheral interrupts
	INTCONbits.GIE = 1; // turn on global interrupts
	T1CONbits.TMR1ON = 1; // turn on timer1
	vsync = 3; // initial state

	unsigned char first[2] = { 1, 1 };
	unsigned char gameover[2] = { 0, 0 };
	unsigned char garbage[2] = { 0, 0 };

	unsigned char flag;
	unsigned char comp;
	unsigned char seed;

	unsigned char col1;
	unsigned char col2;
	
	unsigned char prev_x;
	unsigned char prev_y;
	unsigned char prev_r;

	piece[0] = 0;
	posx[0] = 3;
	posy[0] = 1;
	rot[0] = 0;
	delay[0] = 0;
	score[0] = 0;
	grav[0] = 0;
	bag[0] = 0x7E;

	block_write(2, 0, 0x00);

	piece[1] = 0;
	posx[1] = 15;
	posy[1] = 1;
	rot[1] = 0;
	delay[1] = 0;
	score[1] = 0;
	grav[1] = 0;
	bag[1] = 0x7E;

	block_write(14, 0, 0x00);
	
	// infinite loop
	while (1)
	{
		seed++;

		// loop for each player
		for (p=0; p<2; p++)
		{
			seed++;

			// if gameover, start play again?
			if (gameover[p] > 0)	
			{
				if ((p == 0 && (PORTAbits.RA4 == 0 || PORTAbits.RA5 == 0)) ||
					(p == 1 && (PORTBbits.RB4 == 0 || PORTBbits.RB5 == 0)))
				{	
					gameover[p] = 0;

					// reset values
					piece[p] = 0;
					posx[p] = 3 + 12 * p;
					posy[p] = 1;
					rot[p] = 0;
					delay[p] = 0;
					score[p] = 0;
					grav[p] = 0;
					bag[p] = 0x7E;
					garbage[p] = 0;

					// reset field
					if (p == 0)
					{
						for (i=2; i<10; i++)
						{
							block_write(i, 0, 0xFF);
						}

						for (i=1; i<21; i++)
						{
							for (j=1; j<11; j++)
							{
								block_write(j, i, 0x00);
							}
						}

						for (i=1; i<11; i++)
						{
							block_write(i, 21, 0xFF);
						}
					}
					else
					{
						for (i=14; i<22; i++)
						{
							block_write(i, 0, 0xFF);
						}

						for (i=1; i<21; i++)
						{
							for (j=13; j<23; j++)
							{
								block_write(j, i, 0x00);
							}
						}

						for (i=13; i<23; i++)
						{
							block_write(i, 21, 0xFF);
						}
					}

					block_write(2 + 12 * p, 0, 0x00);
				}
				else continue;
			}		

			if (p == 0)
			{
				col1 = P1COL1; // magenta
				col2 = P1COL2; // green
			}
			else
			{
				col1 = P2COL1; // cyan
				col2 = P2COL2; // red
			}

			// store previous state
			prev_x = posx[p];
			prev_y = posy[p];
			prev_r = rot[p];

			// drop due to gravity
			grav[p]++;
			if (score[p] < 224)
			{
				if (grav[p] >= (32 - (score[p] >> 3))) // increasing speed
				{
					grav[p] = 0;
					posy[p]++;
				}
			}
			else
			{
				if (grav[p] >= 4) // max speed
				{
					grav[p] = 0;
					posy[p]++;
				}
			}
			
			// not descending
			if (posy[p] == prev_y)
			{
				// check buttons
				if ((p == 0 && PORTAbits.RA1 == 0) ||
					(p == 1 && PORTBbits.RB1 == 0)) // down
				{
					seed++;

					if (delay[p] == 0)
					{
						grav[p] = 0;
						posy[p]++;
					}

					delay[p]++;
					if (delay[p] >= 2) delay[p] = 0;
				}
				else if ((p == 0 && PORTAbits.RA3 == 0) ||
					(p == 1 && PORTBbits.RB3 == 0)) // left
				{
					seed++;

					if (delay[p] == 0)
					{
						if (posx[p] < 23) posx[p]++;
					}

					delay[p]++;
					if (delay[p] >= 4) delay[p] = 0;
				}
				else if ((p == 0 && PORTAbits.RA2 == 0) ||
					(p == 1 && PORTBbits.RB2 == 0)) // right
				{
					seed++;
			
					if (delay[p] == 0)
					{
						if (posx[p] > 0) posx[p]--;
					}

					delay[p]++;
					if (delay[p] >= 4) delay[p] = 0;
				}
				else if ((p == 0 && PORTAbits.RA4 == 0) ||
					(p == 1 && PORTBbits.RB4 == 0)) // rotate ccw
				{
					seed++;

					if (delay[p] == 0)
					{
						if (piece[p] >= 2 && piece[p] <= 4) // isz
						{
							rot[p] = (rot[p] ^ 0x01);
						}
						else if (piece[p] == 6) // o
						{
							rot[p] = 0x00;
						}
						else // jlt
						{
							rot[p] = ((rot[p] + 1) & 0x03);
						}
					}

					delay[p] = 1;
				}
				else if ((p == 0 && PORTAbits.RA5 == 0) ||
					(p == 1 && PORTBbits.RB5 == 0)) // rotate cw
				{
					seed++;

					if (delay[p] == 0)
					{
						if (piece[p] >= 2 && piece[p] <= 4) // isz
						{
							rot[p] = (rot[p] ^ 0x01);
						}
						else if (piece[p] == 6) // o
						{
							rot[p] = 0x00;
						}
						else // jlt
						{
							rot[p] = ((rot[p] - 1) & 0x03);
						}
					}

					delay[p] = 1;
				}
				else delay[p] = 0;
			}

			// if moved
			if (posx[p] != prev_x ||
				posy[p] != prev_y ||
				rot[p] != prev_r ||
				first[p] > 0)
			{
				first[p] = 0;

				// erase piece
				for (i=0; i<4; i++)
				{
					block_replace(prev_x, prev_y+i, col1, 0x00);
					block_replace(prev_x+1, prev_y+i, col1, 0x00);
					block_replace(prev_x+2, prev_y+i, col1, 0x00);
					block_replace(prev_x+3, prev_y+i, col1, 0x00);				
				}

				flag = 0;

				// check for collision
				if (piece[p] < 3) // map_jli
				{
					for (i=0; i<4; i++)
					{
						comp = (unsigned char)((piece[p]<<6)+(rot[p]<<4)+(i<<2));

						if (map_jli[comp] != 0x00)
						{
							if (block_read(posx[p], posy[p]+i) != 0x00)
							{
								flag = 1;
								break;
							}
						}
						if (map_jli[comp+1] != 0x00)
						{
							if (block_read(posx[p]+1, posy[p]+i) != 0x00)
							{
								flag = 1;
								break;
							}
						}
						if (map_jli[comp+2] != 0x00)
						{
							if (block_read(posx[p]+2, posy[p]+i) != 0x00)
							{
								flag = 1;
								break;
							}
						}
						if (map_jli[comp+3] != 0x00)
						{
							if (block_read(posx[p]+3, posy[p]+i) != 0x00)
							{
								flag = 1;
								break;
							}
						}
					}
				}
				else if (piece[p] < 6) // map_szt
				{
					for (i=0; i<3; i++)
					{
						comp = (unsigned char)(((piece[p]-3)*18)+(rot[p]*9)+(i*3));

						if (map_szt[comp] != 0x00)
						{
							if (block_read(posx[p], posy[p]+i) != 0x00)
							{
								flag = 1;
								break;
							}
						}
						if (map_szt[comp+1] != 0x00)
						{
							if (block_read(posx[p]+1, posy[p]+i) != 0x00)
							{
								flag = 1;
								break;
							}
						}
						if (map_szt[comp+2] != 0x00)
						{
							if (block_read(posx[p]+2, posy[p]+i) != 0x00)
							{
								flag = 1;
								break;
							}
						}
					}
				}
				else // map_o
				{
					for (i=0; i<2; i++)
					{
						comp = (unsigned char)(i*3);

						if (map_o[comp] != 0x00)
						{
							if (block_read(posx[p], posy[p]+i) != 0x00)
							{
								flag = 1;
								break;
							}
						}
						if (map_o[comp+1] != 0x00)
						{
							if (block_read(posx[p]+1, posy[p]+i) != 0x00)
							{
								flag = 1;
								break;
							}
						}
						if (map_o[comp+2] != 0x00)
						{
							if (block_read(posx[p]+2, posy[p]+i) != 0x00)
							{
								flag = 1;
								break;
							}
						}
					}
				}

				// if collision, set to previous state
				if (flag == 1)
				{
					// if descending, will make stuck
					if (posy[p] != prev_y)
					{
						// check for game over
						if (prev_y == 1)
						{
							flag = 3;
						}
						else
						{
							flag = 2;
						}
					}

					posx[p] = prev_x;
					posy[p] = prev_y;
					rot[p] = prev_r;
				}

				if (flag == 0 || flag == 1)
				{
					// redraw piece
					if (piece[p] < 3) // map_jli
					{
						for (i=0; i<4; i++)
						{
							comp = (unsigned char)((piece[p]<<6)+(rot[p]<<4)+(i<<2));

							if (map_jli[comp] != 0x00) block_write(posx[p], posy[p]+i, col1);
							if (map_jli[comp+1] != 0x00) block_write(posx[p]+1, posy[p]+i, col1);
							if (map_jli[comp+2] != 0x00) block_write(posx[p]+2, posy[p]+i, col1);
							if (map_jli[comp+3] != 0x00) block_write(posx[p]+3, posy[p]+i, col1);
						}
					}
					else if (piece[p] < 6) // map_szt
					{
						for (i=0; i<3; i++)
						{
							comp = (unsigned char)(((piece[p]-3)*18)+(rot[p]*9)+(i*3));

							if (map_szt[comp] != 0x00) block_write(posx[p], posy[p]+i, col1);
							if (map_szt[comp+1] != 0x00) block_write(posx[p]+1, posy[p]+i, col1);
							if (map_szt[comp+2] != 0x00) block_write(posx[p]+2, posy[p]+i, col1);
						}
					}
					else // map_o
					{
						for (i=0; i<2; i++)
						{
							comp = (unsigned char)(i*3);

							if (map_o[comp] != 0x00) block_write(posx[p], posy[p]+i, col1);
							if (map_o[comp+1] != 0x00) block_write(posx[p]+1, posy[p]+i, col1);
							if (map_o[comp+2] != 0x00) block_write(posx[p]+2, posy[p]+i, col1);
						}
					}
				}
				else
				{
					// redraw piece now stuck
					if (piece[p] < 3) // map_jli
					{
						for (i=0; i<4; i++)
						{
							comp = (unsigned char)((piece[p]<<6)+(rot[p]<<4)+(i<<2));

							if (map_jli[comp] != 0x00) block_write(posx[p], posy[p]+i, col2);
							if (map_jli[comp+1] != 0x00) block_write(posx[p]+1, posy[p]+i, col2);
							if (map_jli[comp+2] != 0x00) block_write(posx[p]+2, posy[p]+i, col2);
							if (map_jli[comp+3] != 0x00) block_write(posx[p]+3, posy[p]+i, col2);
						}
					}
					else if (piece[p] < 6) // map_szt
					{
						for (i=0; i<3; i++)
						{
							comp = (unsigned char)(((piece[p]-3)*18)+(rot[p]*9)+(i*3));

							if (map_szt[comp] != 0x00) block_write(posx[p], posy[p]+i, col2);
							if (map_szt[comp+1] != 0x00) block_write(posx[p]+1, posy[p]+i, col2);
							if (map_szt[comp+2] != 0x00) block_write(posx[p]+2, posy[p]+i, col2);
						}
					}
					else // map_o
					{
						for (i=0; i<2; i++)
						{
							comp = (unsigned char)(i*3);

							if (map_o[comp] != 0x00) block_write(posx[p], posy[p]+i, col2);
							if (map_o[comp+1] != 0x00) block_write(posx[p]+1, posy[p]+i, col2);
							if (map_o[comp+2] != 0x00) block_write(posx[p]+2, posy[p]+i, col2);
						}
					}

					// check for game over
					if (flag == 3)
					{
						gameover[p] = 1;
					}
					else
					{
						comp = 0;
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
